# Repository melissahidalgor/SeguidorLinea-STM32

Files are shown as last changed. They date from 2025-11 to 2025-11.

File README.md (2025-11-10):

# 🚗 Proyecto: Carrito Seguidor de Línea con Lógica Difusa (Fuzzy Logic)
## Resumen del Proyecto

Este proyecto consiste en el diseño e implementación de un carrito móvil capaz de seguir una línea negra utilizando un sistema de control basado en Lógica Difusa (Fuzzy Logic).

La Lógica Difusa permite que el carrito tome decisiones adaptativas y fluidas al modificar la velocidad de sus motores en función de la intensidad de la línea detectada por los sensores. Esto resulta en un control más robusto y efectivo para sistemas inherentemente no lineales.

## 💻 Hardware y Componentes

| Componente | Conexión/ Tecnología| Función Principal |
| :--- | :---: | :--- |
| **STM32F411 BlackPill** | Microcontrolador | Utilizado por su capacidad de procesamiento con punto flotante |
| **TCRT5000** | ADC1 (Canales 4, 5, y 6) | Sensor de línea, detectan la intensidad de la luz infrarroja reflejada por la línea |
| **TB6612FNG** | GPIO/PWM | Puente H que maneja la potencia y dirección de los motores DC |

## ⚙️ Implementación de Lógica Difusa

1. **Fuzzificación (Entradas ADC):** Se calcula el grado de pertenencia (*Dentro o Fuera*) de cada entrada del sensor (*Izquierdo, Centro, Derecho*) mediante el uso de funciones de membresía (*Funciones Triangulares*).

2.  **Inferencias (Reglas Lógicas):** Se establecieron reglas simplificadas basadas en que solo un sensor a la vez debería detectar la línea dado el grosor de la línea y la separación entre sensores.

| Condición |Salida (Control de Motores) | 
| :--- | :---: |
| Sensor Izquierdo Dentro| Motor Izquierdo (Baja) / Motor Derecho (Alta) -Giro Derecha |
| Sensor Centro Dentro| Motor Izquierdo (Media) / Motor Derecho (Media) -Avanzar Recto |
| Sensor Derecho Dentro| Motor Izquierdo (Alta) / Motor Derecho (Baja) - Giro a la Izquierda |

3. **Defuzzificación (Salidas PWM):** Se utiliza el centroide para convertir la salida difusa (Baja, Media, Alta) en un valor numérico de PWM (0 a 800).

## 🎥 Video 
[https://drive.google.com/file/d/1-XZC_Tf9S0zmL3UJ1JFDIxQtHfUZZFCX/view?usp=sharing](https://drive.google.com/file/d/1-XZC_Tf9S0zmL3UJ1JFDIxQtHfUZZFCX/view?usp=sharing)

[https://drive.google.com/file/d/1YVrNEFv-BSSDAJJgz_M3N77wPq2cuvl0/view?usp=sharing](https://drive.google.com/file/d/1YVrNEFv-BSSDAJJgz_M3N77wPq2cuvl0/view?usp=sharing)

## 🖼️ Montaje

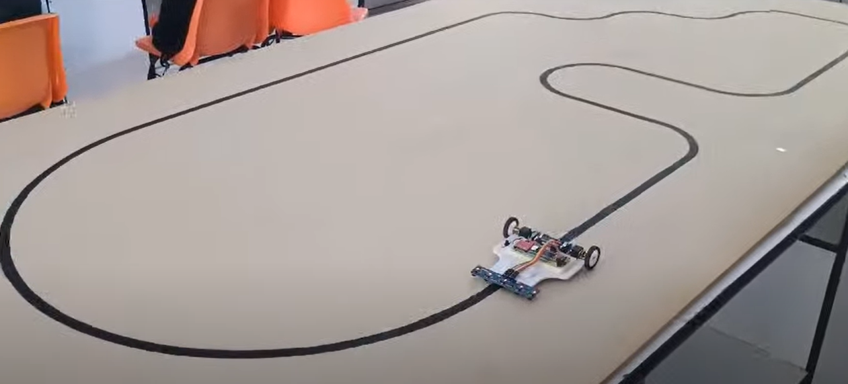
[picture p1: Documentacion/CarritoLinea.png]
Texto alternativo


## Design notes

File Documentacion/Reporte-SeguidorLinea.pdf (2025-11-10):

## CARRITO SEGUIDOR DE LÍNEA

## IMPLEMENTANDO LÓGICA DIFUSA

Alvarado Lagunes María José 1

, Fuantos Díaz Jorge Eduardo 2

, Hidalgo Rodríguez Melissa 3

Departamento de Sistemas Electrónicos, Universidad Autónoma de Aguascalientes, Av. Universidad # 940, Ciudad Universitaria, C.P. 20100, Aguascalientes, Ags. México

{al331869 1

, al19 2

, al262931 3} @edu.uaa.mx

Resumen: En el presente reporte se presenta el procedimiento detallado para la implementación y construcción de un carrito seguidor de línea utilizando lógica difusa como su principio de programación. El desarrollo del proyecto incluye la construcción del carrito mediante modelado 3D, y el diseño y la conexión de los componentes eléctricos necesarios para operar correctamente. Para el control del carrito, se emplearon funciones de membresía que permitieron definir los estados de entrada y salida del sistema. También, se establecieron reglas de inferencia para determinar la lógica de control, tomando a consideración las entradas de los sensores. Además, se describen las diferentes pruebas realizadas para la calibración del sistema, así como los desafíos encontrados durante el desarrollo y las soluciones propuestas para la optimización del carrito.

Palabras Clave: Calibración, Control, Lógica Difusa, Reglas

### 1 Introducción

Los inicios de la lógica difusa se sitúan en la década de 1960 cuando el matemático e ingeniero Lotfi A. Zadeh formuló esta teoría para abordar problemas que involucraran incertidumbre y subjetividad al permitir valores continuos en un rango entre 0 y 1. La lógica difusa en el carrito seguidor de línea permite tomar decisiones basadas en la intensidad en la que se detecta la línea y así modificar la velocidad de los motores para conservar su rumbo. Si bien la lógica difusa es la parte primordial en el control del carrito seguidor de línea, para el desarrollo del carrito se analizaron otros aspectos importantes como la mecánica, la electrónica y la estructura física del carrito.

### 2 Métodos

La metodología empleada contempla los conceptos y el desarrollo de las actividades siguientes:

### 2.1 Marco Teórico

Para el diseño del carrito seguidor de línea se toman las aportaciones teóricas de diversos autores en las áreas del conocimiento que se mencionan a continuación:

Lógica Difusa: Es una extensión de la lógica clásica que permite manejar conceptos con grados intermedios en lugar de valores booleanos (falso y verdadero). Es comúnmente utilizada para modelar la imprecisión o incertidumbre en diversas aplicaciones, como sistemas de control, inteligencia artificial o toma de decisiones.

En lugar de trabajar con valores binarios, a lógica difusa está enfocada en representar las variables con grados de pertenencia que varían entre 0 y 1, siendo útil en situaciones donde la información puede ser más ambigua o imprecisa, lo que permite una aproximación más cercana a como se procesa y se maneja normalmente.

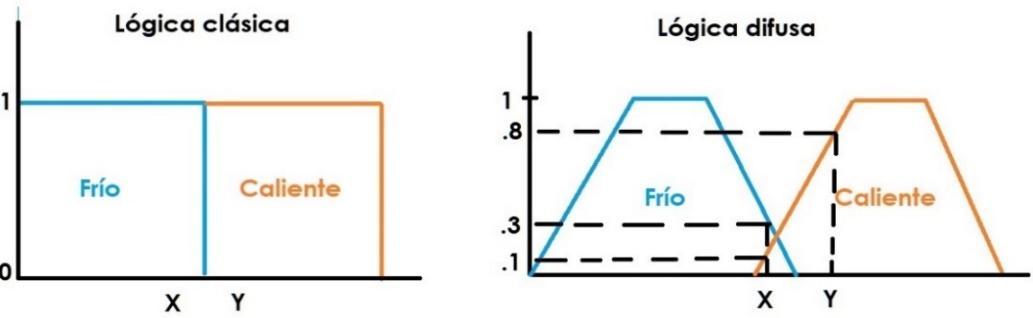
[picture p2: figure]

Fig. 1. Comparación entre la Lógica Clásica y Lógica Difusa

Las aplicaciones de este tipo de lógica abarcan desde el control de diferentes procesos industriales, ingeniería robótica, y la inteligencia artificial. [1]

Existen diferentes tipos de conjuntos difusos que pueden ser utilizados para el modelaje de los fenómenos a representar, sin embargo, existen algunos de estos que son más comúnmente utilizados, debido a su facilidad de computación. Entre los conjuntos, o funciones, más utilizados se encuentran las mostradas en al Fig. 2.

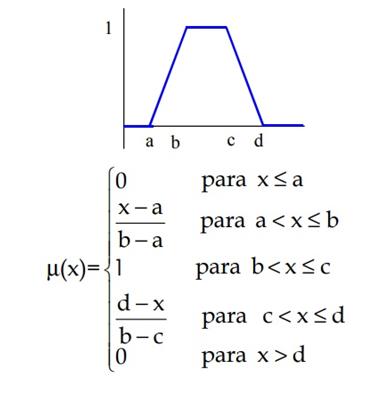
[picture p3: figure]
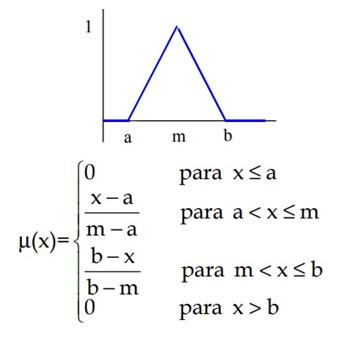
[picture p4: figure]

a. Función Triangular | b. Función Trapezoidal

Fig. 2. Funciones de Pertenencia

En base a estos conceptos, los pasos para el control difuso se enlistan a continuación:

1. Fuzzificación: Los valores de entrada se transforman en conceptos lingüísticos difusos mediante las funciones de pertenencia.
2. Inferencia: En esta etapa se enlazan las cantidades difusas a través de reglas lógicas utilizando operadores lógicos como OR, AND y NOT
3. Defuzzificación: Se convierten las salidas difusas en valores numéricos. Esto implica encontrar valores representativos para la salida, generalmente se emplea el centroide de la función de membresía. [2]

Sensores de línea: Los sensores de línea son dispositivos que consisten en un LED emisor de luz infrarroja y un fototransistor receptor, El LED emite una luz infrarroja que es reflejada por las superficies cercanas. Dependiendo del color y las propiedades de la superficie, la cantidad de luz reflejada varía, siguiendo este principio, se pueden producir diferentes tipos de respuesta en forma de señal, lo que es útil para la implementación de programas, según se requiera.

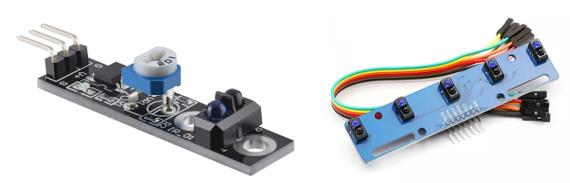
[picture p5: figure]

Fig. 3. Sensores infrarrojos

### 2.2 Construcción del Carrito Seguidor de Línea

Lo primero que se realizó fue un sondeo de los materiales posibles con los que se podía realizar el carrito seguidor, la selección de los materiales utilizados se basó en su tamaño y peso, puesto que son factores primordiales para la eficiencia del carrito.

Para la estructura del carrito seguidor de línea se tomaron mediciones de cada uno de los componentes que se montaría en la base, y se diseñó la misma de manera que se tuviese una buena distribución del peso, intentando mantener ligera la parte del frente. Se buscó tener dimensiones similares para el ancho y el largo, para así lograr una forma lo más cuadrada posible con el fin de tener un mejor control en las vueltas cerradas. La base de la Fig. 4 se imprimió en una impresora 3D con material PLA.

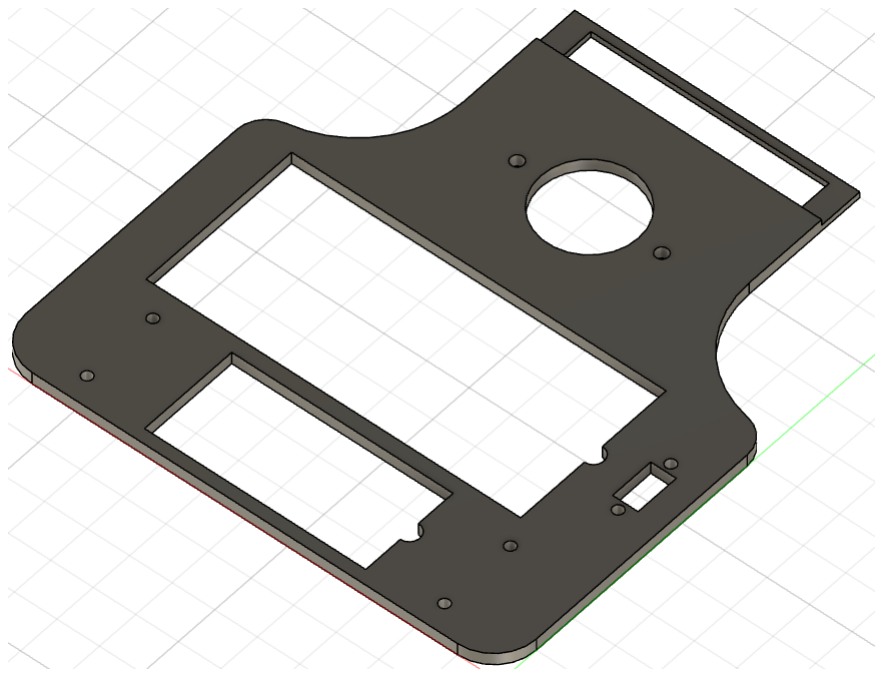
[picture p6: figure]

Fig. 4. Base del carrito

Para el control se implementó la placa de desarrollo Blackpill con el microcontrolador STM32F411, en donde para el control de los motores se configuró el TIM4 a 10 kHz y se habilitaron los canales 1 y 2 como PWM. Para la lectura de los sensores infrarrojos se habilitaron los canales 4, 5 y 6 del ADC1 y se habilitó el DMA para almacenar la lectura de los 3 canales. Además, se habilitó el USART1 para capturar los valores del ADC y formar las funciones de pertenencia (Fig. 5).

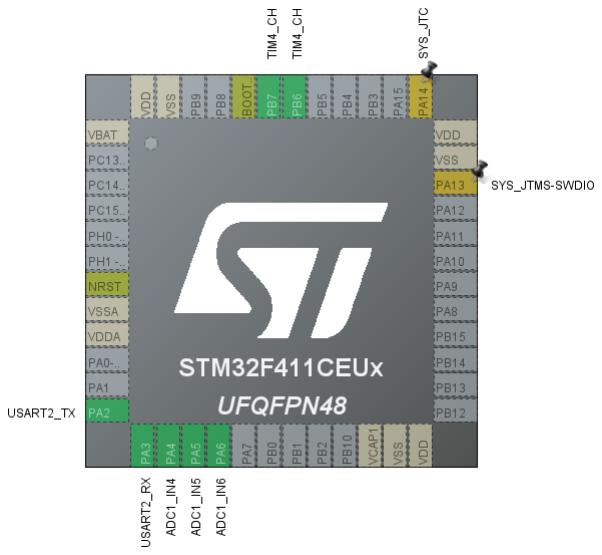
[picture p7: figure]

Fig. 5. Configuraciones de la Blackpill

Finalmente, se conectaron los componentes como se muestra en la Fig. 6, integrando el módulo TB6612FNG para el control de los motores y dos baterías AAA para alimentar el circuito, junto con un switch de encendido y apagado.

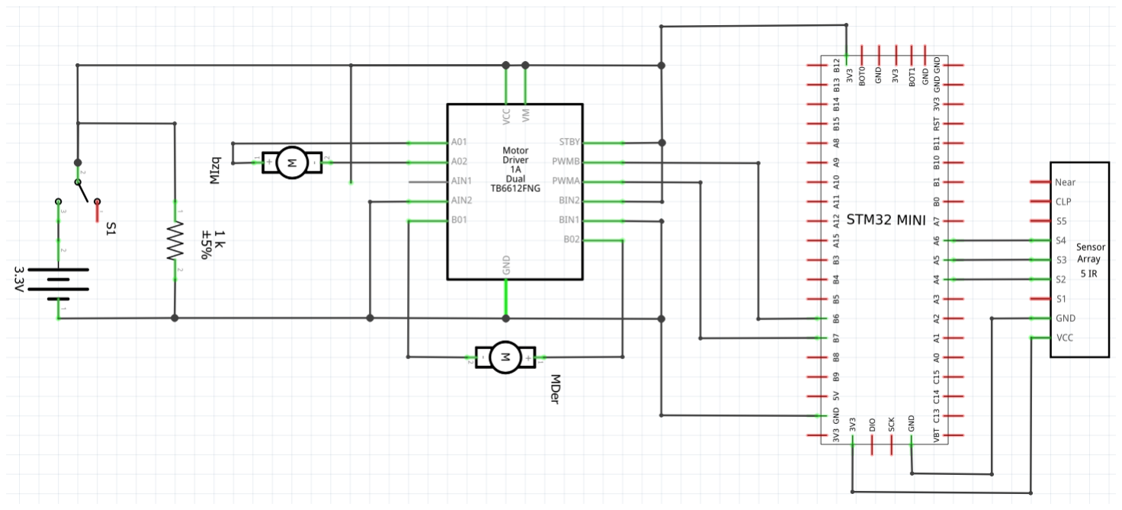
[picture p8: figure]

Fig. 6. Conexiones del Carrito

### 2.3 Diseño del Control Difuso

### 2.3.1 Fuzzificación

Para el control difuso se comenzó por realizar las mediciones mostradas en la Tabla 1, en base a estos resultados se estableció que la función de pertenencia para cada uno de los sensores es la que se muestra en la Figura 7.

Tabla 1. Muestreo de datos

Posición | Sensor Izquierdo Sensor Centro | Sensor Derecho

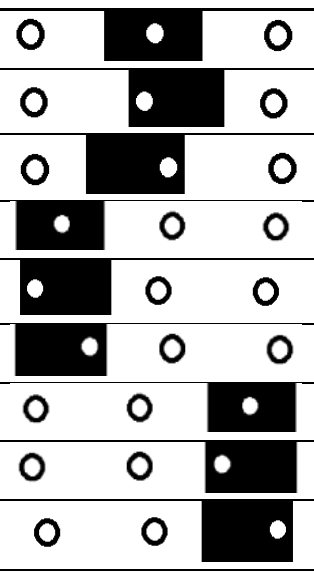
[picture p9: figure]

3420 | 560 | 3420
3436 | 750 | 3442
4240 | 760 | 3440
580 | 3440 | 3440
660 | 3450 | 3450
670 | 3430 | 3430
3465 | 3380 | 580
3380 | 3460 | 577
3460 | 3445 | 579

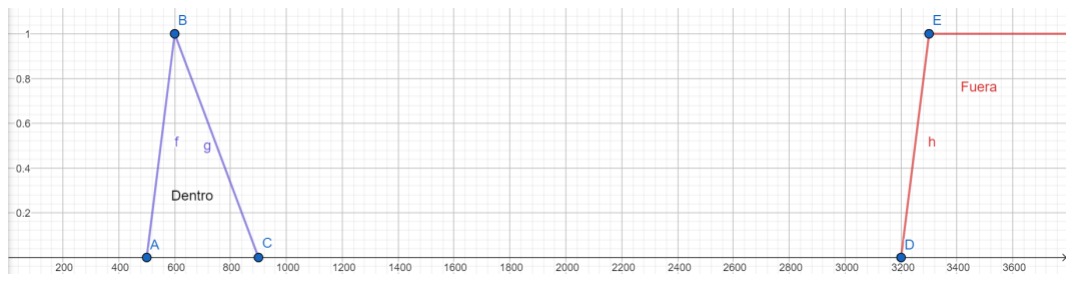
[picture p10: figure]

Fig. 7. Funciones de Pertenencia Sensores

### 2.3.2 Inferencia

Nótese que no hay casos en los que dos o más sensores tomen lectura de la línea, por lo que para las reglas difusas para determinar la velocidad de cada motor se simplificaron como se muestra a continuación:

- Sensor Izquierda (Dentro), Sensor Centro (Fuera) y Sensor Derecho (Fuera) = Motor Izquierdo (Baja) y Motor Derecho (Alta)
- Sensor Izquierda (Fuera), Sensor Centro (Dentro) y Sensor Derecho (Fuera) = Motor Izquierdo (Media) y Motor Derecho (Media)
- Sensor Izquierda (Fuera), Sensor Centro (Fuera) y Sensor Derecho (Dentro) = Motor Izquierdo (Alta) y Motor Derecho (Baja)
- Sensor Izquierda (Fuera), Sensor Centro (Fuera) y Sensor Derecho (Fuera) = Velocidad de motores anterior

Las combinaciones no mostradas no son posibles en condiciones normales, sin embargo, en caso de presentarse, los motores se mantendrían con la velocidad anterior.

### 2.3.1 Defuzzificación

Tomando en cuenta que el valor máximo posible en el PWM es de 800 y que el valor mínimo experimental del PWM para mover el carrito es de 300, se formaron las funciones de pertenencia mostradas en la Fig. 8. Es importante notar que el Motor Derecho por la distribución de pesos tiene 20 unidades de PWM menos para tener la misma velocidad que el Motor Izquierdo.

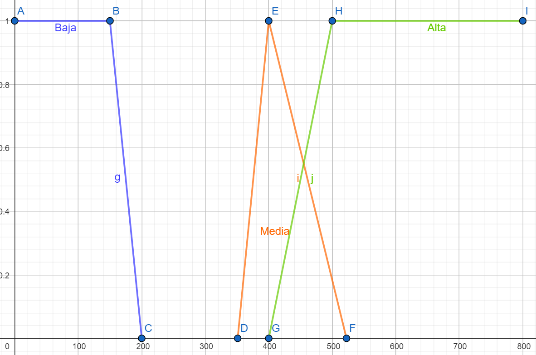
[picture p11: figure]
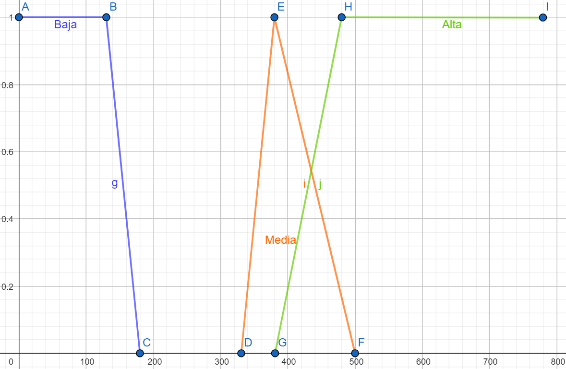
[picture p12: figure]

a. Motor Derecho. | b. Motor Izquierdo

Fig. 8. Funciones de Pertenencia Motores

Para la etapa de defuzzificación se calculó el valor del PWM mediante el cálculo del centroide de las figuras formadas en las funciones de pertenencia. El mayor número de figuras posibles y se muestran en la Fig. 9.

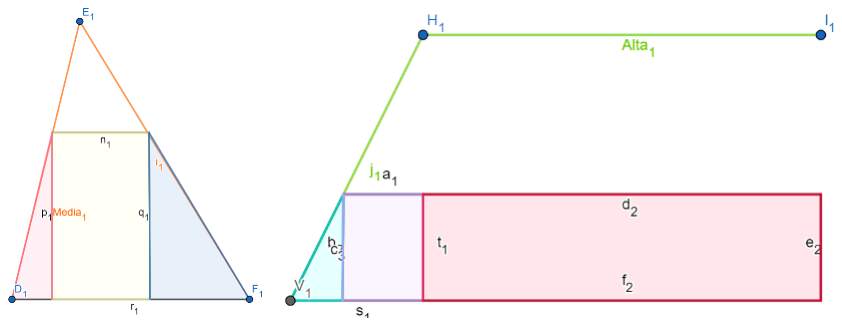
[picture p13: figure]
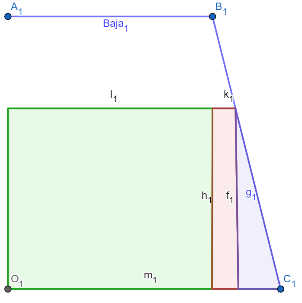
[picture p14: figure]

a. Baja | b. Media | c. Alta

Fig. 9. Figuras para el Cálculo de Centroides

### 3 Resultados

En la Fig. 10 se muestra el montaje completo del carrito seguidor de línea.

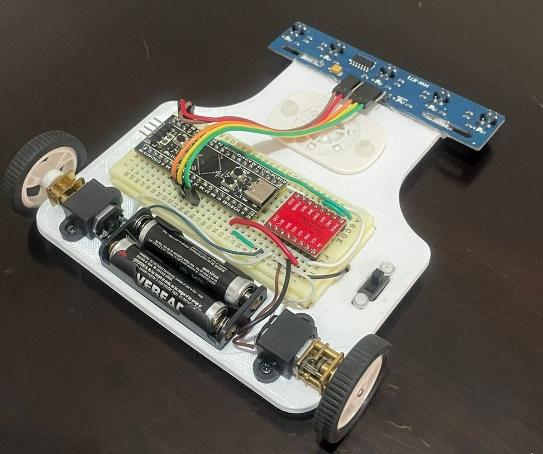
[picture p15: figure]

Fig. 10. Carrito Seguidor de Línea.

Al analizar el comportamiento del carrito se notó como tenía un buen giro en las curvas cerradas gracias a los valores de velocidad escogidos al crear las funciones de pertenencia (Fig. 11). Un detalle inusual que se observó en el carrito es que en ciertas pruebas al ir en línea recta su velocidad aumentaba de manera significativa, mientras que en otras se quedaba en un valor relativamente bajo de velocidad en las mismas condiciones, sin embargo, no es un aspecto que afecte al carrito para el seguimiento de la línea.

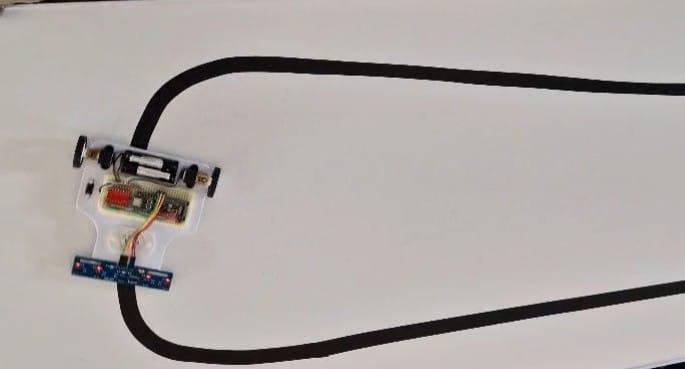
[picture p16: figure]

Fig. 11. Carrito Seguidor de Línea en Funcionamiento.

### 5 Conclusiones

La implementación de lógica difusa para el carrito seguidor de línea ha resultado ser una solución efectiva para el control de un sistema no lineal. La lógica difusa permite que el carrito seguidor tome decisiones adaptativas conforme el carrito avanzaba, modificando la velocidad en función de la situación en la que se encontraba el carrito. Un aspecto para mejorar en el carrito sería integrar los dos sensores de los extremos laterales en el módulo, si bien en un inicio no se integraron por el temor a la complejidad aumentara, ya analizadas las funciones de pertenencia se llegó a la conclusión de que podrían ser utilizados como una extensión de los sensores laterales ya configurados, permitiendo que en caso de haber una curva muy cerrada el carrito tenga más tiempo de reacción. La experiencia obtenida con este proyecto abre la puerta a futuras aplicaciones de la lógica difusa en otros sistemas de control, como robots móviles, drones, entre otros.

### 6 Bibliografía y Referencias

[1] E. Bello, «Lógica Difusa o Fuzzy Logic: Qué es y cómo funciona + Ejemplos,» iebschool, 15 12 2021. [En línea]. Available: https://www.iebschool.com/blog/fuzzy-logic-que-es-big-data/. [Último acceso: 18 06 2024].
[2] G. Hamburg, «Automatización Control Difuso,» [En línea]. Available: https://www.gunt.de/images/download/Conocimientos-bsicos-control-difuso_spanish.pdf. [Último acceso: 19 06 2024].

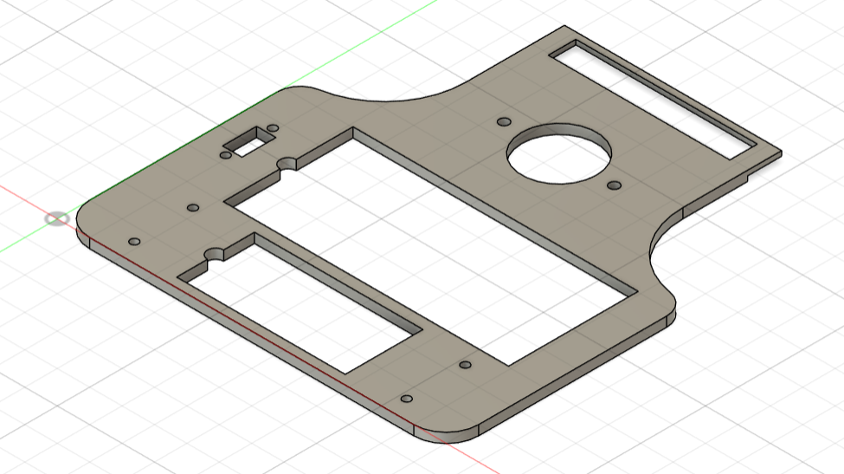
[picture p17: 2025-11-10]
Modelo3D/Base.png

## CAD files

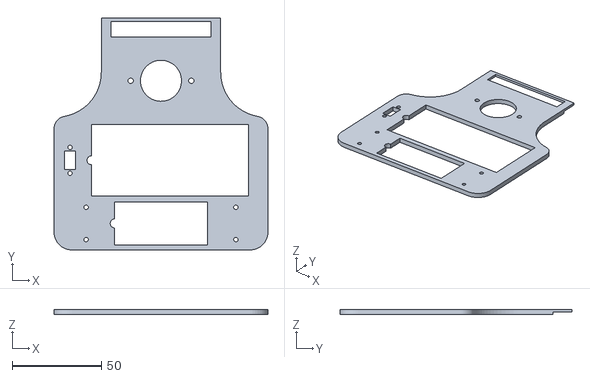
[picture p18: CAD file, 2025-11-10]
Modelo3D/Base v3.stl
120.0 x 130.0 x 3.00

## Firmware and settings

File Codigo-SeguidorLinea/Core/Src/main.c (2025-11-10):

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
/* Includes ------------------------------------------------------------------*/
#include "main.h"

/* USER CODE BEGIN Includes */
#include <stdio.h>
#include <string.h>
#include <math.h>
/* USER CODE END Includes */

/* USER CODE BEGIN PD */
#define NA    0
#define BAJA  1
#define MEDIA 2
#define ALTA  3

/* USER CODE END PD */

ADC_HandleTypeDef hadc1;
DMA_HandleTypeDef hdma_adc1;

TIM_HandleTypeDef htim4;

UART_HandleTypeDef huart2;

/* USER CODE BEGIN PV */
uint16_t val1=0;
uint16_t val2=0;
uint16_t val3=0;
uint16_t rawValues[3];
uint16_t pwmI, pwmD;
float mu, muI, muC, muD, motorI, motorD, x, x2, cenTri, cenTri2, cenRec, areaTri, areaTri2, areaRec, areaRec2, cenRec2;

char msg[20];
/* USER CODE END PV */

void SystemClock_Config(void);
static void MX_GPIO_Init(void);
static void MX_DMA_Init(void);
static void MX_ADC1_Init(void);
static void MX_TIM4_Init(void);
static void MX_USART2_UART_Init(void);
/* USER CODE BEGIN 0 */
uint8_t convCompleted =0;

/* USER CODE END 0 */

/**
  * @brief  The application entry point.
  * @retval int
  */
int main(void)
{
  /* MCU Configuration--------------------------------------------------------*/

  /* Reset of all peripherals, Initializes the Flash interface and the Systick. */
  HAL_Init();

  /* Configure the system clock */
  SystemClock_Config();

  /* Initialize all configured peripherals */
  MX_GPIO_Init();
  MX_DMA_Init();
  MX_ADC1_Init();
  MX_TIM4_Init();
  MX_USART2_UART_Init();
  /* USER CODE BEGIN 2 */
  HAL_ADC_Start_DMA(&hadc1, (uint32_t *) rawValues, 3);
  HAL_TIM_PWM_Start(&htim4, TIM_CHANNEL_1);
  HAL_TIM_PWM_Start(&htim4, TIM_CHANNEL_2);

  /* USER CODE END 2 */

  /* Infinite loop */
  /* USER CODE BEGIN WHILE */
  while (1)
  {
	  for(uint8_t i=0; i < hadc1.Init.NbrOfConversion; i++){
		  val1= (uint16_t) rawValues[0];
		  val2= (uint16_t) rawValues[1];
		  val3= (uint16_t) rawValues[2];
	  }

	  /*sprintf(msg, "Sensor1: %d \t", val1);
	  HAL_UART_Transmit(&huart2, (uint8_t *) msg, strlen(msg), HAL_MAX_DELAY);
	  sprintf(msg, "Sensor2: %d \t", val2);
	  HAL_UART_Transmit(&huart2, (uint8_t *) msg, strlen(msg), HAL_MAX_DELAY);
	  sprintf(msg, "Sensor3: %d \t\n\r", val3);
	  HAL_UART_Transmit(&huart2, (uint8_t *) msg, strlen(msg), HAL_MAX_DELAY);

	  HAL_Delay(1000);*/

	  // Determinar Mu
	  	// Para Izquierdo
	  	if(val1 > 3000)
	  		muI = 1;
	  	else if(val1 < 600)
	  		muI = (val1-500.0)/(600-500);
	  	else
	  		muI = (900.0-val1)/(900-600);

	  	// Para Centro
	  	if(val2 > 3000)
	  		muC = 1;
	  	else if (val2 < 600)
	  		muC = (val2-500.0)/(600-500);
	  	else
	  		muC = (900.0-val2)/(900-600);

	  	// Para Derecho
	  	if(val3 > 3000)
	  		muD = 1;
	  	else if(val3 < 600)
	  		muD = (val3-500.0)/(600-500);
	  	else
	  		muD = (900.0-val3)/(900-600);


	  // Reglas de Pertenencia
	  	if((muI < muC) && (muI < muD)){
	  		mu = muI;
	  		motorI = BAJA;
	  		motorD = ALTA;
	  	}
	  	else if((muC < muI) && (muC < muD)){
	  		mu = muC;
	  		motorD = MEDIA;
	  		motorI = MEDIA;
	  	}
	  	else if((muD < muC) && (muD < muI)){
	  		mu = muD;
	  		motorD = BAJA;
	  		motorI = ALTA;
	  	}
	  	else{
	  		//pwmI = 0;
	  		//pwmD = 500;
	  		motorI = NA;
	  		motorI = NA;
	  	}

	  // Desifusificar
	  	// Motor Izquierdo
	  	if(motorI == ALTA){
	  		x = (500-400)*mu + 400;
	  		cenTri = 2*(x-400)/3 + 400;
	  		cenRec = (500-x) + x;
	  		areaTri = (x-400)*mu/2;
	  		areaRec = (500-x)*mu;
	  		areaRec2 = (800-500)*mu;
	  		cenRec2 = (800-500)/2 + 500;

	  		pwmI = (areaTri*cenTri + areaRec*cenRec + areaRec2*cenRec2)/(areaTri + areaRec + areaRec2);

	  	}
	  	else if(motorI == MEDIA){
			x = (400-350)*mu + 350;
			cenTri = 2*(x-350)/3 + 350;
			areaTri = (x-350)*mu/2;

			x2 = 500 - (520-400)*mu;
			cenTri2 = (520-x2)/3 + x2;
			areaTri2 = (520-x2)*mu/2;

			cenRec = (x2-x) + x;
			areaRec = (x2-x)*mu;

			pwmI = (areaTri*cenTri + areaTri2*cenTri2 + areaRec*cenRec)/(areaTri + areaTri2 + areaRec);
		}
	  	else if(motorI == BAJA){
	  		x = 200 - (200-150)*mu;
	  		cenTri = (200-x)/3 + x;
	  		cenRec = (x-150) + 150;
	  		areaTri = (200-x)*mu/2;
	  		areaRec = (x-150)*mu;
	  		areaRec2 = (150)*mu;
	  		cenRec2 = (150)/2;

	  		pwmI = (areaTri*cenTri + areaRec*cenRec + areaRec2*cenRec2)/(areaTri + areaRec + areaRec2);
	  	}

	  	// Motor Derecho
	  	if(motorD == ALTA){
	  		x = (480-380)*mu + 380;
	  		cenTri = 2*(x-380)/3 + 380;
	  		cenRec = (480-x) + x;
	  		areaTri = (x-380)*mu/2;
	  		areaRec = (480-x)*mu;
	  		areaRec2 = (780-480)*mu;
	  		cenRec2 = (780-480)/2 + 480;

	  		pwmD = ceil((areaTri*cenTri + areaRec*cenRec + areaRec2*cenRec2)/(areaTri + areaRec + areaRec2));
	  	}
	  	else if(motorD == MEDIA){
			x = (380-330)*mu + 330;
			cenTri = 2*(x-330)/3 + 330;
			areaTri = (x-330)*mu/2;

			x2 = 480 - (500-380)*mu;
			cenTri2 = (500-x2)/3 + x2;
			areaTri2 = (500-x2)*mu/2;

			cenRec = (x2-x) + x;
			areaRec = (x2-x)*mu;

			pwmD = (areaTri*cenTri + areaTri2*cenTri2 + areaRec*cenRec)/(areaTri + areaTri2 + areaRec);
		}
	  	else if(motorD == BAJA){
	  		x = 180 - (180-130)*mu;
	  		cenTri = (180-x)/3 + x;
	  		cenRec = (x-130) + 130;
	  		areaTri = (180-x)*mu/2;
	  		areaRec = (x-130)*mu;
	  		areaRec2 = (130)*mu;
	  		cenRec2 = (130)/2;

	  		pwmD = ceil((areaTri*cenTri + areaRec*cenRec + areaRec2*cenRec2)/(areaTri + areaRec + areaRec2));
	  	}

	  	TIM4 -> CCR1 = pwmD;		//B6-DER (-20)
	    TIM4 -> CCR2 = pwmI;		// B7-IZQ

    /* USER CODE END WHILE */

    /* USER CODE BEGIN 3 */
  }
  /* USER CODE END 3 */
}

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

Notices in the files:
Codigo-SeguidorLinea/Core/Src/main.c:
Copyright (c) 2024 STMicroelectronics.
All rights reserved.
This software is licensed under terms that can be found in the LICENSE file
